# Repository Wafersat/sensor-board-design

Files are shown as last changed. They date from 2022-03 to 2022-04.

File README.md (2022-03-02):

# WSS Sensor Board
WSS's Sensor Board design.
## Why sensor board?
Because the final goal of the WSS is to integrate everything onto a custom PCB, a sensor board allows us to test out the various sensor functionality without having to be tied down to one particular hardware. We can evaluate the board design on multiple MCUs. Modular design is always preferred in the development phase. 
## What MCU?
Right now we're looking at the RP2040 from Raspberry Pi.
## Why RP2040?
- Lots of documentation and reference designs
- Cheap, at $1 a pop, and plenty available
- Dev boards very available and many have open-source designs
- Good enough for our purposes
## Why CircuitPython?
Adafruit Industries, who builds and maintains CircuitPython, had written libraries for many of the sensors we use. Using CP instead of MicroPython speeds up the development process. Plus, I'm pretty sure their coding quality is miles ahead of mine.

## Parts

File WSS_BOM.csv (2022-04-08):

Component | Description | Part | References | Value | Footprint | Quantity Per PCB | Datasheet | MANUFACTURER | MAXIMUM_PACKAGE_HEIGHT | STANDARD | LCSC | AVAILABILITY | MP | PACKAGE | PRICE | Arrow Part Number | Arrow Price/Stock | Manufacturer_Name | Manufacturer_Part_Number | Mouser Part Number | Mouser Price/Stock | PARTREV
1 |  | S8411-45R | BT1 | S8411-45R | BAT_S8411-45R | 1 |  | Harwin | 4.25mm | Manufacturer Recommendations
2 | Unpolarized capacitor, small symbol | C_Small | C25 C26 | 12pF | C_0603_1608Metric | 2 | ~
3 | Unpolarized capacitor, small symbol | C_Small | C18 | 470pF | C_0603_1608Metric | 1 | ~
4 | Unpolarized capacitor, small symbol | C_Small | C12 C24 | 1nF | C_0603_1608Metric | 2 | ~
5 | Unpolarized capacitor, small symbol | C_Small | C22 | 22nF | C_0603_1608Metric | 1 | ~
6 | Unpolarized capacitor, small symbol | C_Small | C6 C20 C21 C27 C28 C29 C30 C31 C33 C34 | 100nF | C_0603_1608Metric | 10 | ~
7 | Unpolarized capacitor, small symbol | C_Small | C23 | 0.47uF | C_0603_1608Metric | 1 | ~
8 | Unpolarized capacitor, small symbol | C_Small | C1 C2 C3 C4 C5 C7 C8 C9 C15 C32 C35 | 1uF | C_0603_1608Metric | 11 | ~
9 | Unpolarized capacitor, small symbol | C_Small | C19 | 4.7uF | C_0603_1608Metric | 1 | ~
10 | Unpolarized capacitor, small symbol | C_Small | C11 C13 C16 C17 | 10uF | C_0603_1608Metric | 4 | ~
11 | Unpolarized capacitor, small symbol | C_Small | C10 C14 | 22uF | C_0603_1608Metric | 2 | ~
12 | Schottky diode | D_Schottky | D2 | D_Schottky | D_0603_1608Metric | 1 | ~
13 | Light emitting diode | LED | D1 | LED | LED_0603_1608Metric | 1 | ~
14 | Generic connector, single row, 01x08, script generated (kicad-library-utils/schlib/autogen/connector/) | Conn_01x08 | J5 | Arducam | PinHeader_1x08_P2.54mm_Vertical | 1 | ~
15 | Generic connector, single row, 01x08, script generated (kicad-library-utils/schlib/autogen/connector/) | Conn_01x08 | J1 | Conn_01x08 | PinHeader_1x08_P2.00mm_Vertical | 1 | ~
16 | Generic connector, single row, 01x02, script generated (kicad-library-utils/schlib/autogen/connector/) | Conn_01x02 | J9 | Conn_Batt | JST_PH_S2B-PH-SM4-TB_1x02-1MP_P2.00mm_Horizontal | 1 | ~ |  |  |  | C47647
17 | Micro SD Card Socket | Micro_SD_Card | J4 | DM3AT-SF-PEJM5 | HRS_DM3AT-SF-PEJM5 | 1 | http://katalog.we-online.de/em/datasheet/693072010801.pdf
18 |  | U.FL-R-SMT-1(10) | J3 | GPS u.fl | HRS_U.FL-R-SMT-1(10) | 1 |  | Hirose |  | Manufacturer Recommendation |  | Good | U.FL-R-SMT-1_10_ | None | 0.71 USD
19 | DC Barrel Jack | Barrel_Jack | J6 J7 | PV_Jack | BarrelJack_Horizontal | 2 | ~
20 |  | U.FL-R-SMT-1(10) | J2 | Radio u.fl | HRS_U.FL-R-SMT-1(10) | 1 |  | Hirose |  | Manufacturer Recommendation |  | Good | U.FL-R-SMT-1_10_ | None | 0.71 USD
21 | USB 2.0-only Type-C Receptacle connector | USB_C_Receptacle_USB2.0 | J8 | USB_C_Receptacle_USB2.0 | USB_C_Receptacle_XKB_U262-16XN-4BVC11 | 1 | https://www.usb.org/sites/default/files/documents/usb_type-c.zip |  |  |  | C319148
22 | Inductor | L | L1 | 10uH | L_0603_1608Metric | 1 | ~
23 | 4.2A Id, 20V Vds, N-Channel MOSFET, SOT-23 | DMG3414U | Q2 Q3 | DMG3414U | SOT-23 | 2 | http://www.diodes.com/assets/Datasheets/ds31739.pdf
24 | P-MOSFET transistor, gate/drain/source | Q_PMOS_GDS | Q4 Q5 Q6 Q7 Q8 Q9 | Q_PMOS_GDS | DIP-4_W7.62mm | 6 | ~
25 | NPN transistor, base/collector/emitter | Q_NPN_BCE | Q1 | UMT3904T106 | SOT65P210X100-3N | 1 | ~
26 | Resistor, small symbol | R_Small | R24 | 10mR | R_0603_1608Metric | 1 | ~
27 | Resistor, small symbol | R_Small | R14 R21 | 0R1 | R_0603_1608Metric | 2 | ~
28 | Resistor | R | R22 | 1R | R_0603_1608Metric | 1 | ~
29 | Resistor, small symbol | R_Small | R26 | 10R | R_0603_1608Metric | 1 | ~
30 | Resistor, small symbol | R_Small | R33 R34 | 27R | R_0603_1608Metric | 2 | ~
31 | Resistor, small symbol | R_Small | R27 | 100R | R_0603_1608Metric | 1 | ~
32 | Resistor | R | R4 R5 | 470 | R_0603_1608Metric | 2 | ~
33 | Resistor | R | R7 R17 R18 R28 R29 R36 | 1k | R_0603_1608Metric | 6 | ~
34 | Resistor | R | R12 R13 R23 R25 R30 R31 | 4.7k | R_0603_1608Metric | 6 | ~
35 | Resistor, small symbol | R_Small | R15 R16 | 5.1K | R_0603_1608Metric | 2 | ~
36 | Resistor | R | R1 R2 R3 R6 R8 R9 R10 R11 R32 R35 R37 | 10k | R_0603_1608Metric | 11 | ~
37 | Resistor, small symbol | R_Small | R20 | 100k | R_0603_1608Metric | 1 | ~
38 | Resistor, small symbol | R_Small | R19 | 220k | R_0603_1608Metric | 1 | ~
39 | Resistor, small symbol | R_Small | R39 | 383k | R_0603_1608Metric | 1 | ~
40 | Resistor, small symbol | R_Small | R40 | 825k | R_0603_1608Metric | 1 | ~
41 | Resistor, small symbol | R_Small | R38 | 3.74M | R_0603_1608Metric | 1 | ~
42 | Push button switch, generic, two pins | SW_Push | SW1 | RESET | SW_Push_SPST_NO_Alps_SKRK | 1 | ~
43 | Single Pole Single Throw (SPST) switch | SW_SPST | SW3 | SW_BOOTSEL | SW_SPST_B3U-1000P | 1 | ~
44 | Single Pole Single Throw (SPST) switch | SW_SPST | SW2 | SW_RESET | SW_SPST_B3U-1000P | 1 | ~
45 | 1A 20V Fixed LDO Linear Regulator, 3.3V, SOT-89/SOT-223/TO-220/TO-252/TO-263 | AZ1117-3.3 | U12 | AZ1117-3.3 | SOT-223 | 1 | https://www.diodes.com/assets/Datasheets/AZ1117.pdf
46 | 1A 20V Fixed LDO Linear Regulator, 3.3V, SOT-89/SOT-223/TO-220/TO-252/TO-263 | AZ1117-3.3 | U10 | AZ1117H-5.0TRG1 | SOT-223 | 1 | https://www.diodes.com/assets/Datasheets/AZ1117.pdf
47 | 3-in-1 sensor, humidity, pressure, temperature, I2C and SPI interface, 1.71-3.6V, LGA-8 | BME280 | U9 | BME280 | Bosch_LGA-8_2.5x2.5mm_P0.65mm_ClockwisePinNumbering | 1 | https://ae-bst.resource.bosch.com/media/_tech/media/datasheets/BST-BME280-DS002.pdf
48 | IMUs - Inertial Measurement Units VFLGA2.5X3X.86 14L P.5 L.475X.25 | ISM330DHCXTR | U6 | ISM330DHCXTR | LGA-14_2.5X3X0.86_ | 1 | https://www.st.com/resource/en/datasheet/ism330dhcx.pdf |  |  |  |  |  |  |  |  | ISM330DHCXTR | https://www.arrow.com/en/products/ism330dhcxtr/stmicroelectronics?region=nac | STMicroelectronics | ISM330DHCXTR | 511-ISM330DHCXTR | https://www.mouser.co.uk/ProductDetail/STMicroelectronics/ISM330DHCXTR?qs=%252B6g0mu59x7Jv2Xps2dM6Xw%3D%3D
49 | Temperature Voltage and Current Monitor, I2C Interface, MSOP-10 | LTC2990 | U13 | LTC2990 | MSOP-10_3x3mm_P0.5mm | 1 | https://www.analog.com/media/en/technical-documentation/data-sheets/ltc2990.pdf
50 | Prioritized PowerPath Controller, Selects Highest Priority Supply from Three Inputs, –40°C to 85°C, QFN | LTC4417IUF | U17 | LTC4417IUF | QFN-24-1EP_4x4mm_P0.5mm_EP2.6x2.6mm | 1 | https://www.analog.com/media/en/technical-documentation/data-sheets/4417f.pdf
51 | GNSS Module MAX M8, VCC 2.7V to 3.6V | MAX-M8Q | U4 | MAX-M8Q | ublox_MAX | 1 | https://www.u-blox.com/sites/default/files/MAX-M8-FW3_DataSheet_%28UBX-15031506%29.pdf
52 |  | MAX17330X22+ | U14 | MAX17330X22+ | MAX17330X22&plus_ | 1
53 | Low power long range transceiver module, SPI and parallel interface, 915 MHz, spreading factor 6 to12, bandwith 7.8 to 500kHz, -111 to -148 dBm, SMD-16, DIP-16 | RFM95W-915S2 | U2 | RFM95W | XCVR_RFM95W-915S2 | 1 | https://www.hoperf.com/data/upload/portal/20181127/5bfcbea20e9ef.pdf
54 |  | RP2040 | U15 | RP2040 | QFN40P700X700X90-57N | 1 | https://datasheets.raspberrypi.org/rp2040/rp2040_datasheet.pdf
55 | Realtime Clock/Calendar I2C Interface, Low Power, 1.2 V to 5.5 V, MicroCrystal C3 | RV-8523-C3 | U3 | RV-8523-C3 | RTC_SMD_MicroCrystal_C3_2.5x3.7mm | 1 | https://www.microcrystal.com/fileadmin/Media/Products/RTC/Datasheet/RV-8523-C3.pdf
56 |  | SPV1040T | U11 | SPV1040T | SOP65P640X120-8N | 1 |  | ST Microelectronics |  | IPC7351B |  |  |  |  |  |  |  |  |  |  |  | 7
57 | Low power 3D magnetic sensor, I2C interface, SOT-23-6 | TLV493D | U8 | TLV493D | SOT-23-6 | 1 | http://www.infineon.com/dgdl/Infineon-TLV493D-A1B6-DS-v01_00-EN.pdf?fileId=5546d462525dbac40152a6b85c760e80
58 |  | TPS22902BYFPR | U1 U5 | TPS22902BYFPR | TPS22902BYFPR | 2
59 |  | VEML7700-TT | U7 | VEML7700-TT | XDCR_VEML7700-TT | 1 |  | Vishay |  | Manufacturer Recommendation |  |  |  |  |  |  |  |  |  |  |  | 1.3
60 |  | W25Q64JV | U16 | W25Q64JV | WSON-8-1EP_6x5mm_P1.27mm_EP3.4x4mm | 1
61 | Four pin crystal, GND on pins 2 and 4, small symbol | Crystal_GND24_Small | Y1 | XYDBPCNANF-12MHZ | Crystal_SMD_2520-4Pin_2.5x2.0mm | 1 | ~ |  |  |  | C521567
Component Groups: | 61
Component Count: | 118
Fitted Components: | 118
Number of PCBs: | 1
Total components: | 118
Schematic Version: | 0.1
Schematic Date: | 2022-03-04
PCB Variant: | default
BoM Date: | Wednesday, March 30, 2022 at 10:29:13 AM
Schematic Source: | Twinkies.kicad_sch
KiCad Version: | Eeschema (6.0.2-0)

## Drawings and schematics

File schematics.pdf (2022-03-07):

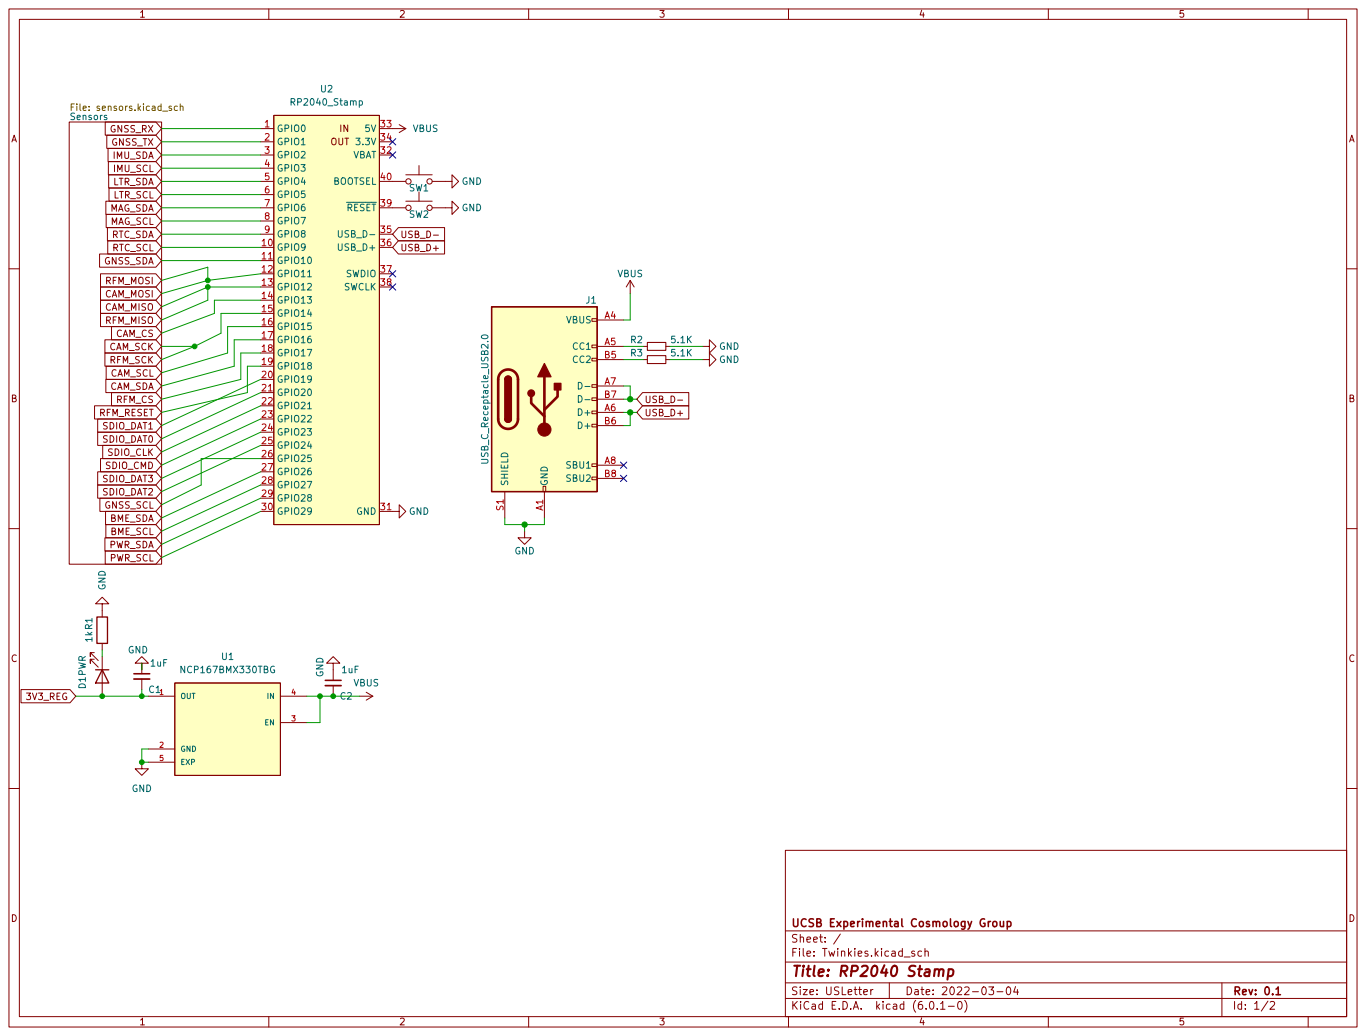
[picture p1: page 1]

File: Twinkies.kicad_sch Sheet: / UCSB Experimental Cosmology Group

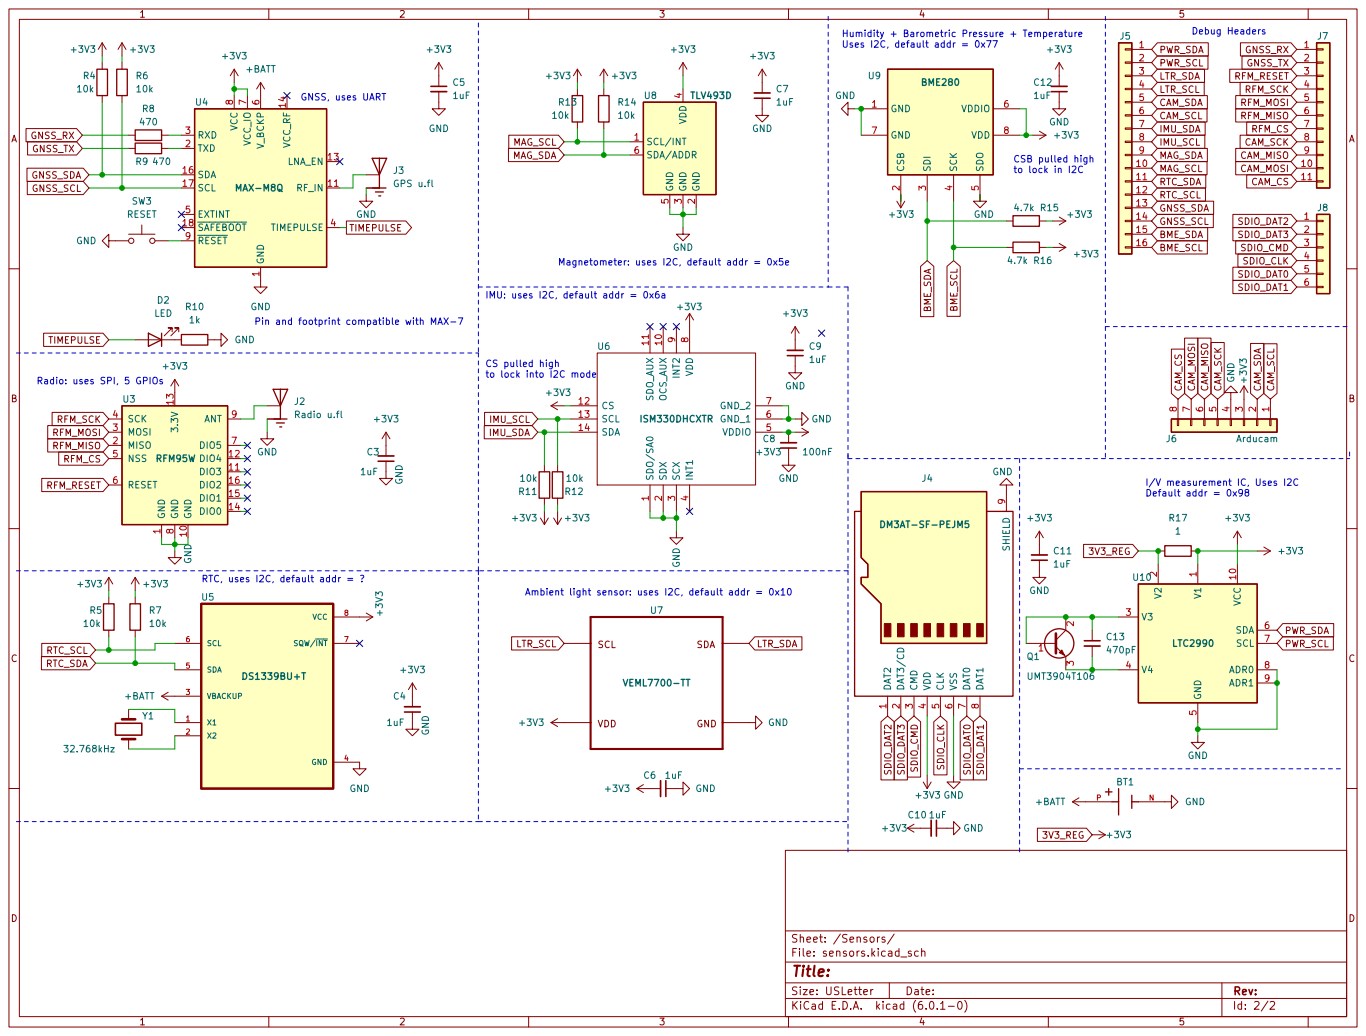
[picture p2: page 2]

5 VDDIO 6 GND 7 VDD 8 U9 BME280 GND

Default addr = 0x98 CSB pulled high

to lock in I2C Magnetometer: uses I2C, default addr = 0x5e

to lock into I2C mode Pin and footprint compatible with MAX-7

1 OCS_AUX 10 SDO_AUX 11 CS 12 SCL 13 SDA 14 SDX

1 GND 10 DIO3 11 DIO4 12 3.3V 13 DIO0 14 DIO1 15 DIO2 16 MISO 2 MOSI 3 SCK 4 NSS 5 RESET 6 DIO5 7 GND

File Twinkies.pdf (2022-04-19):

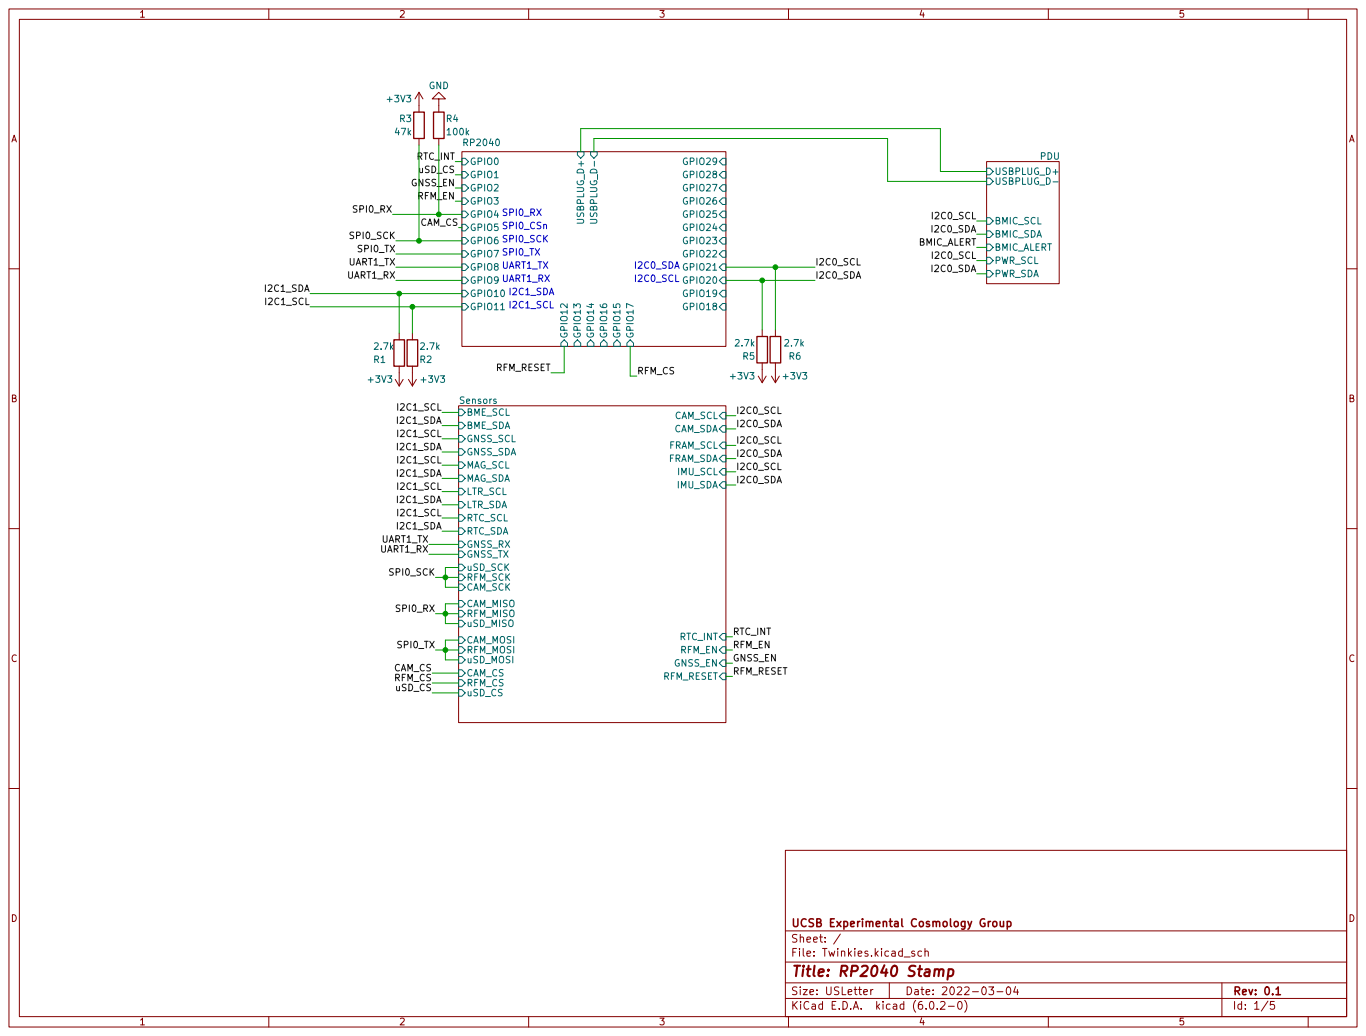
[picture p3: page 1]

File: Twinkies.kicad_sch Sheet: / UCSB Experimental Cosmology Group

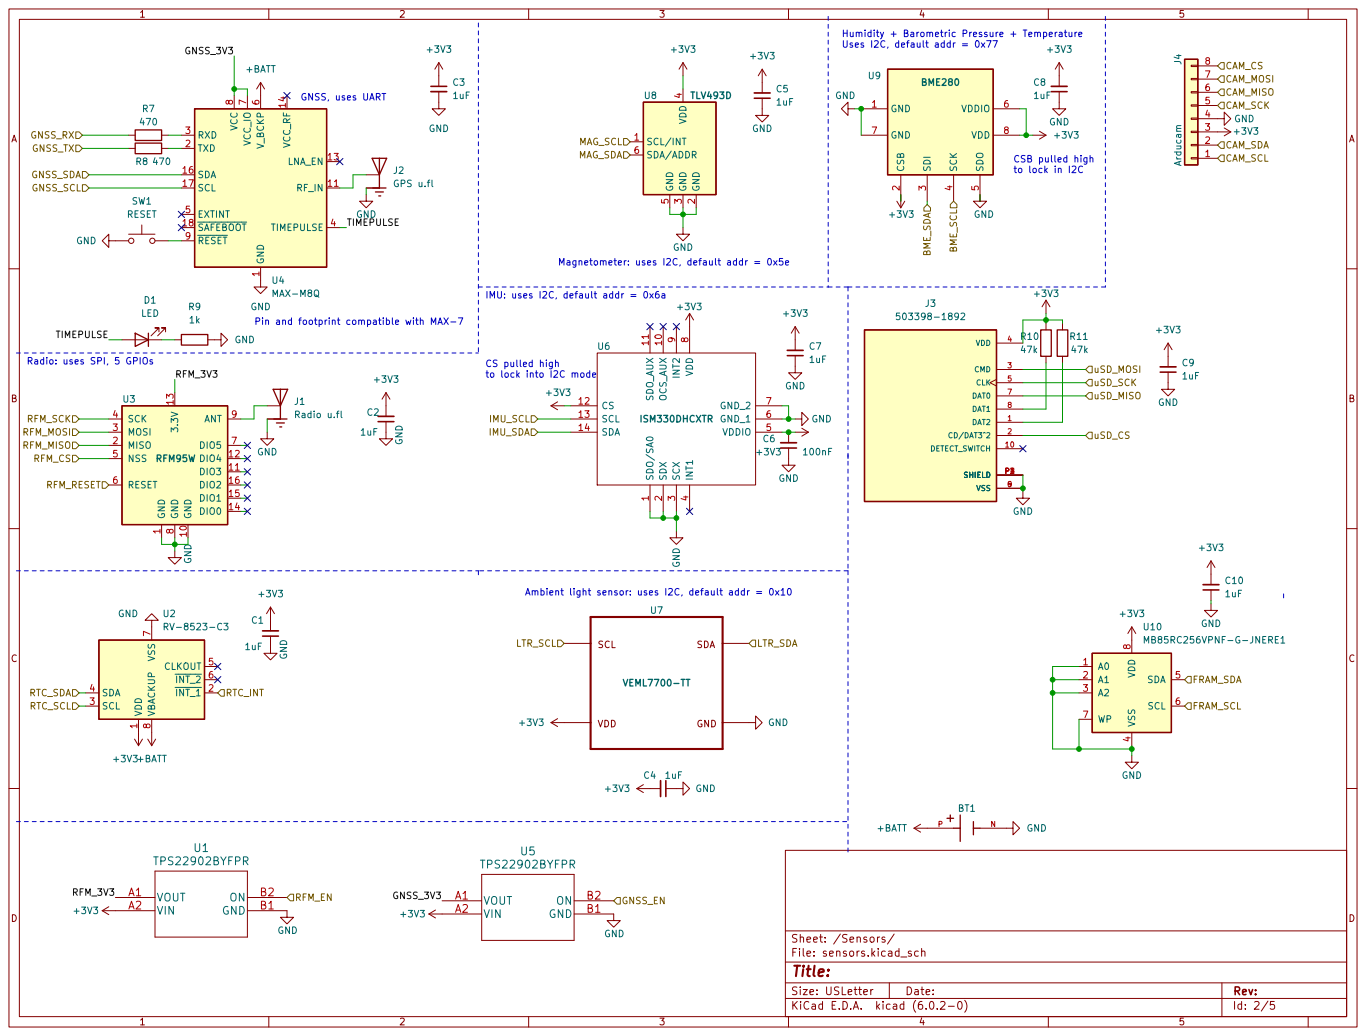
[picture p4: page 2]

5 VDDIO 6 GND 7 VDD 8 U9 BME280 +3V3 GND GND

5 SDA/ADDR 6 U8 TLV493D GND SDO/SA0

Magnetometer: uses I2C, default addr = 0x5e

IMU: uses I2C, default addr = 0x6a CS pulled high

to lock into I2C mode Pin and footprint compatible with MAX-7

J1Radio u.fl GND GND GND

1 OCS_AUX 10 SDO_AUX 11 CS 12 SCL 13 SDA 14 SDX
47k GND GND

1 GND 10 DIO3 11 DIO4 12 3.3V 13 DIO0 14 DIO1 15 DIO2 16 MISO 2 MOSI 3 SCK 4 NSS 5 RESET 6 DIO5 7 GND

File: sensors.kicad_sch Sheet: /Sensors/ GND

1 ~{INT_1} 2 SCL 3 SDA 4 CLKOUT 5 ~{INT_2} 6 VSS

4 SDA 5 SCL 6 WP 7 VDD

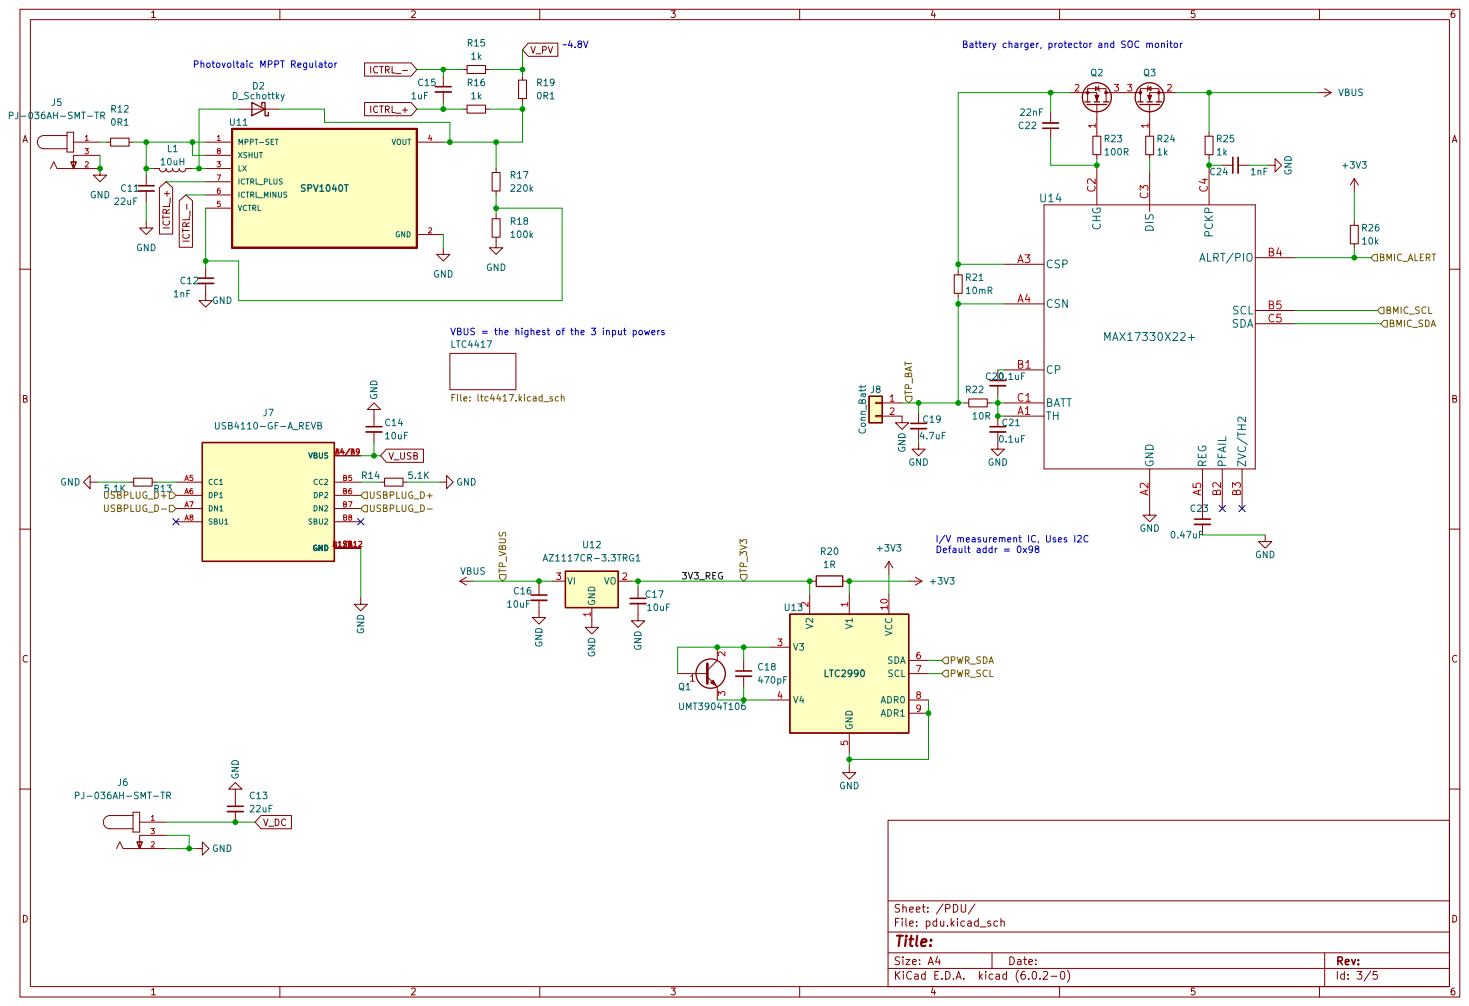
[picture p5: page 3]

File: pdu.kicad_sch Sheet: /PDU/
Id: 3/5 Title:

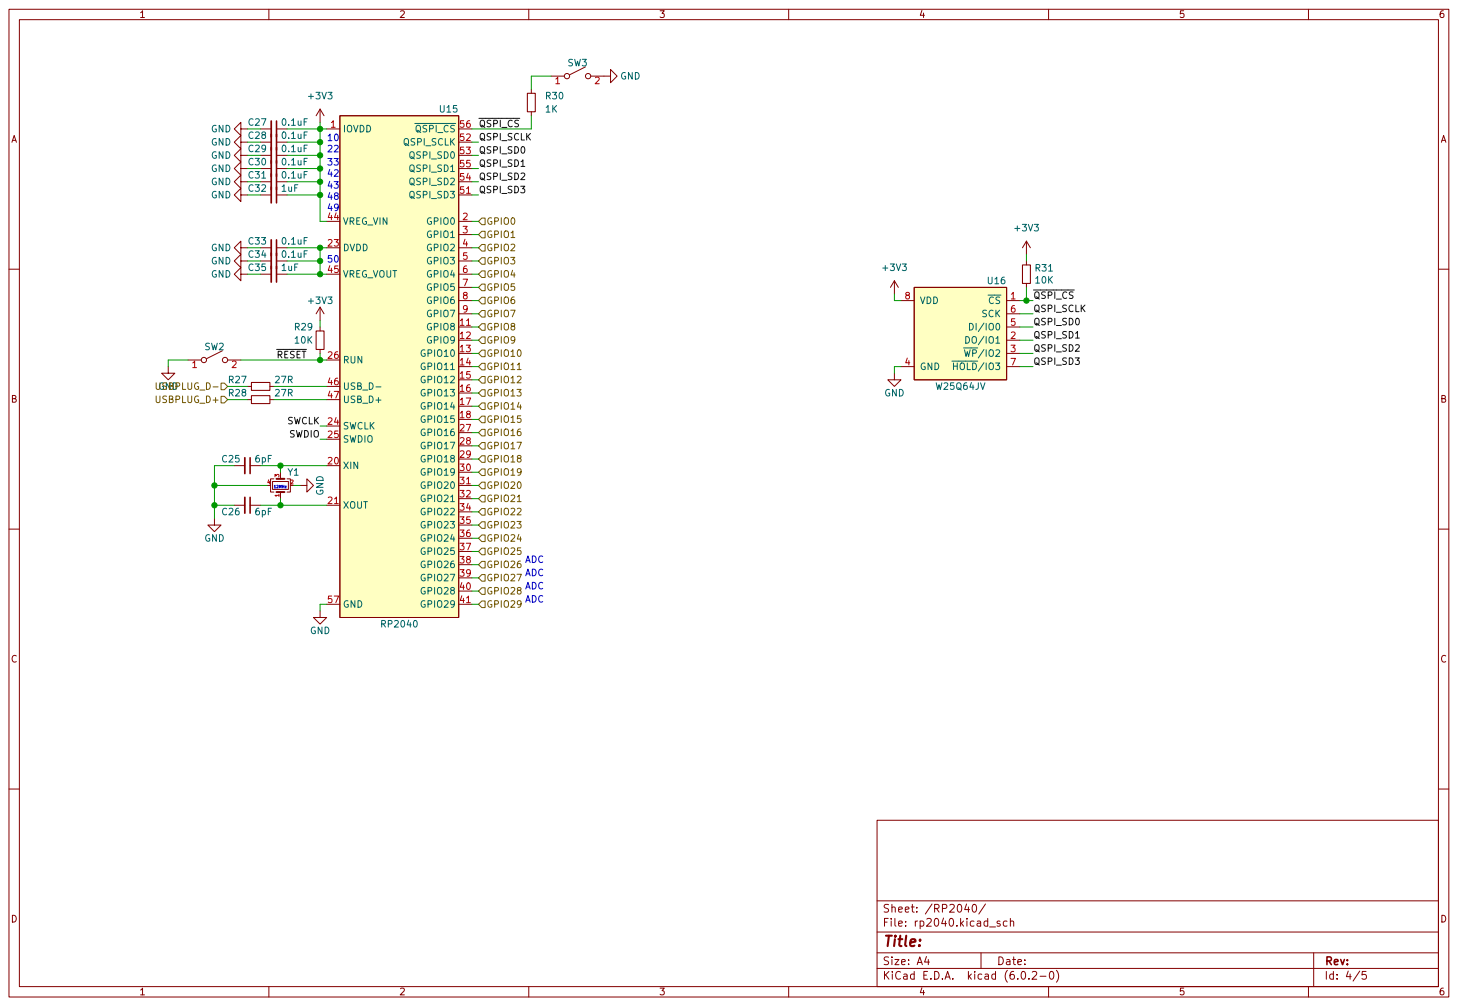
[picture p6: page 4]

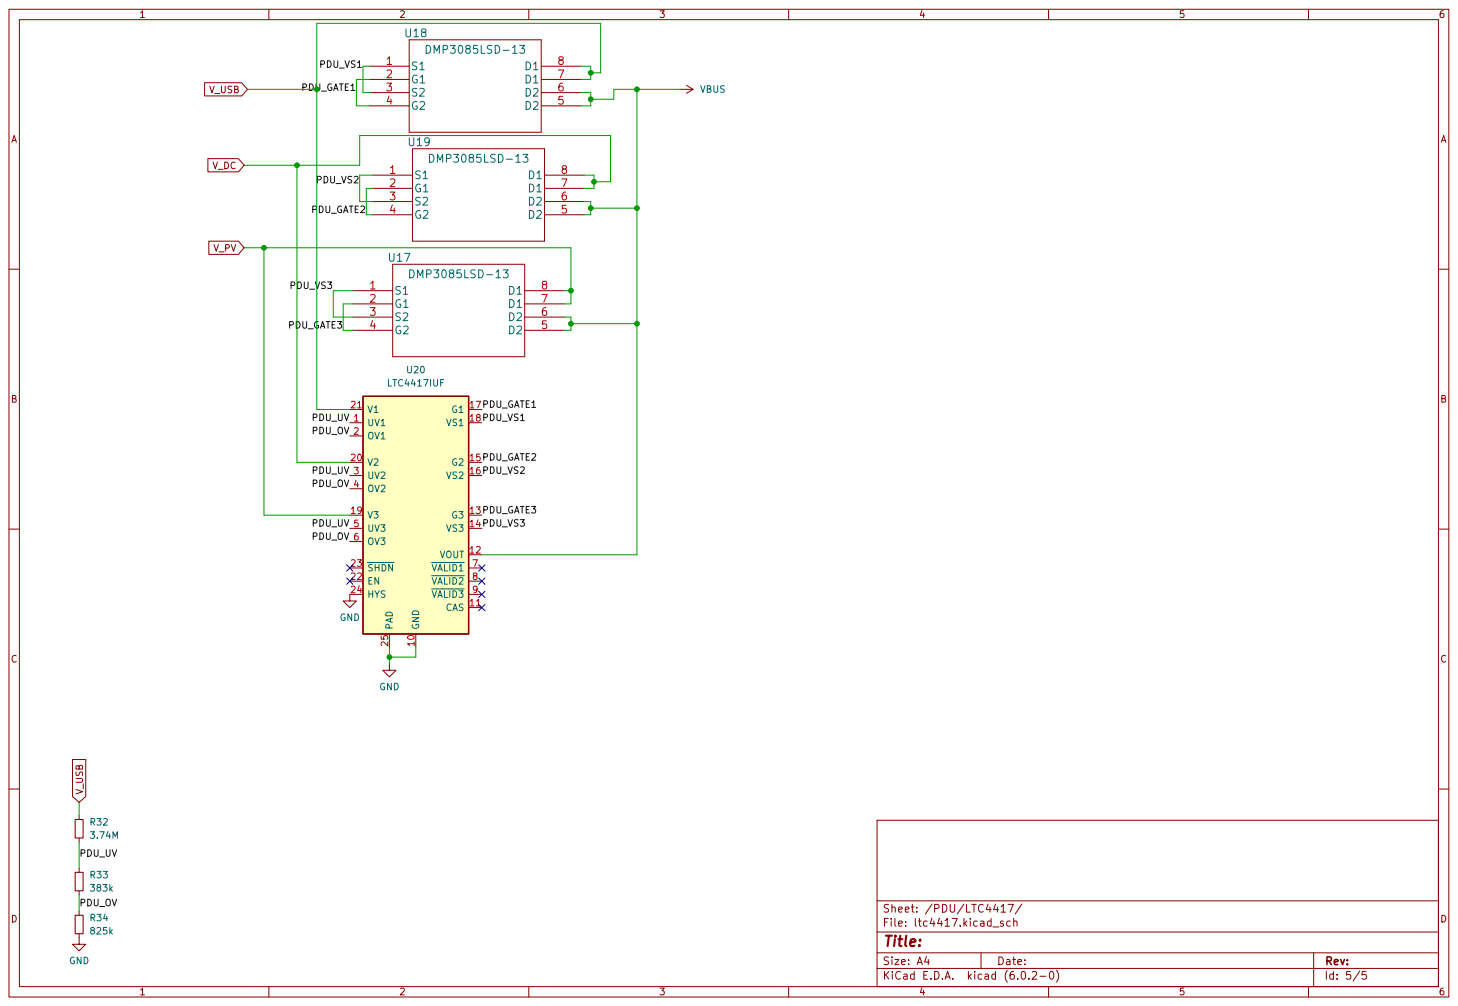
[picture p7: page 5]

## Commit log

2022-02-26 0.1 Schematic
    Schematic as of Feb 25
    [Twinkies.kicad_sch]
2022-03-02 added daughter board
    [sensors.kicad_sch]
2022-03-14 pdu design
    [Twinkies.kicad_pcb, Twinkies.kicad_sch, pdu.kicad_sch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]
2022-04-08 Apr 8
    [Twinkies.kicad_pcb, Twinkies.kicad_sch, WSS_BOM.csv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]
